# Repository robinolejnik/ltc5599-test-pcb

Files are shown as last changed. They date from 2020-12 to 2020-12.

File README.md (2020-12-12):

# ltc5599-test-pcb
This is a test PCB for the LTC5599 30 MHz to 1300 MHz Low Power Direct Quadrature Modulator.

[Schematic](https://raw.githubusercontent.com/robinolejnik/ltc5599-test-pcb/master/ltc5599-test-pcb.pdf)

[Interactive BOM](https://htmlpreview.github.io/?https://github.com/robinolejnik/ltc5599-test-pcb/blob/master/bom/ibom.html)

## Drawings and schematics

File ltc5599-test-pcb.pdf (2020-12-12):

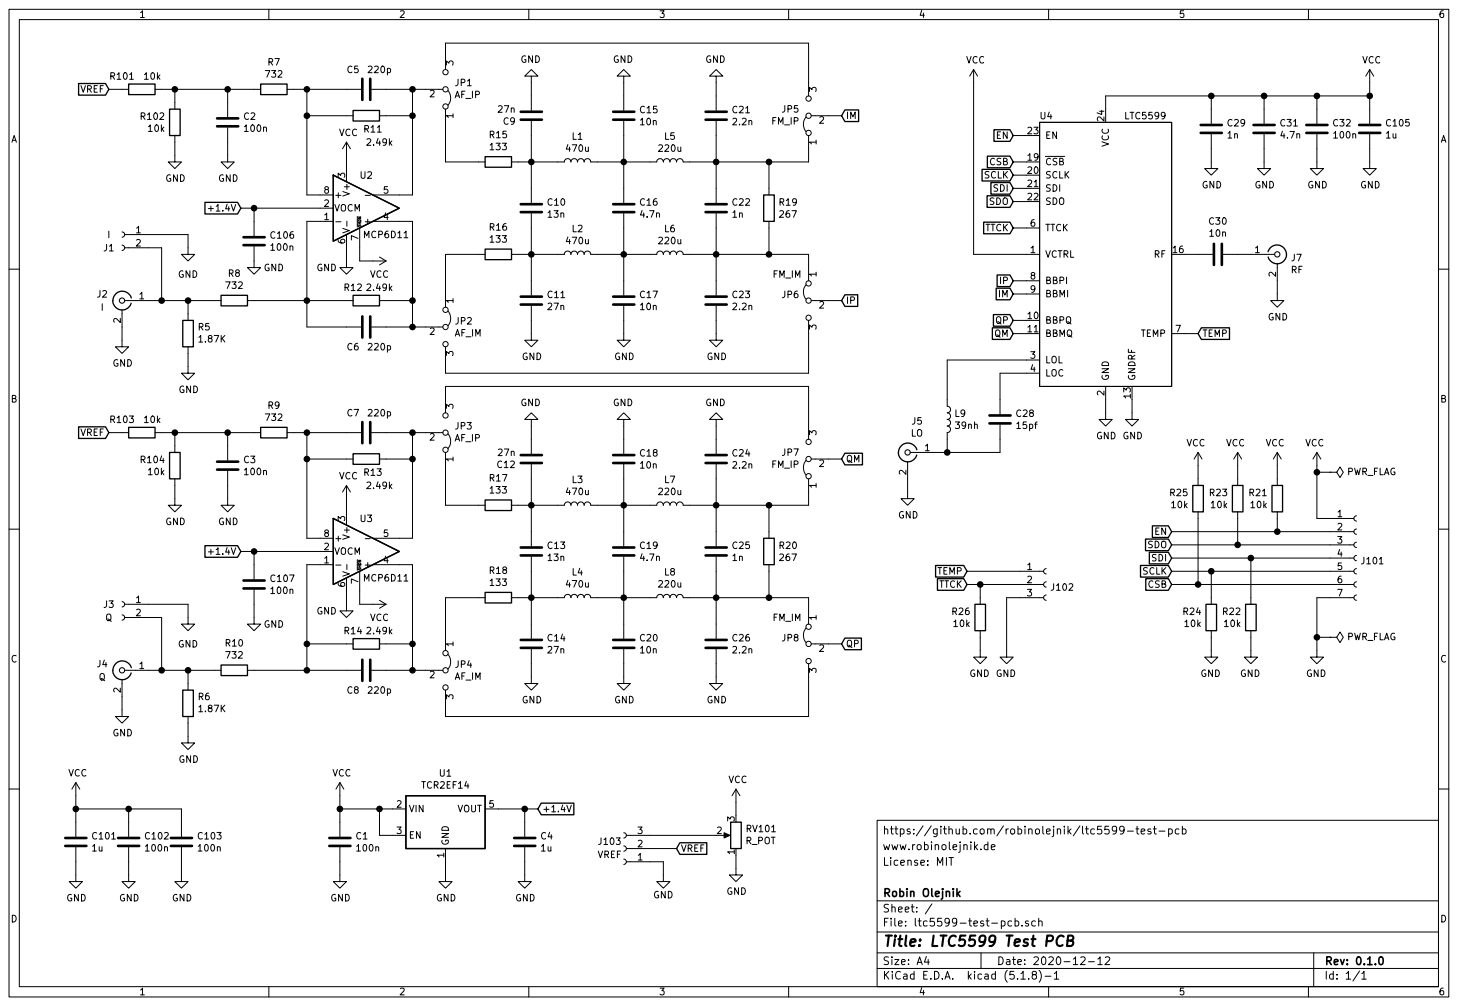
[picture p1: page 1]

2 SCLK 20 SDI 21 SDO 22 EN 23 VCC 24

https://github.com/robinolejnik/ltc5599-test-pcb
License: MIT www.robinolejnik.de

File: ltc5599-test-pcb.sch Sheet: / Robin Olejnik

Id: 1/1 Title: LTC5599 Test PCB

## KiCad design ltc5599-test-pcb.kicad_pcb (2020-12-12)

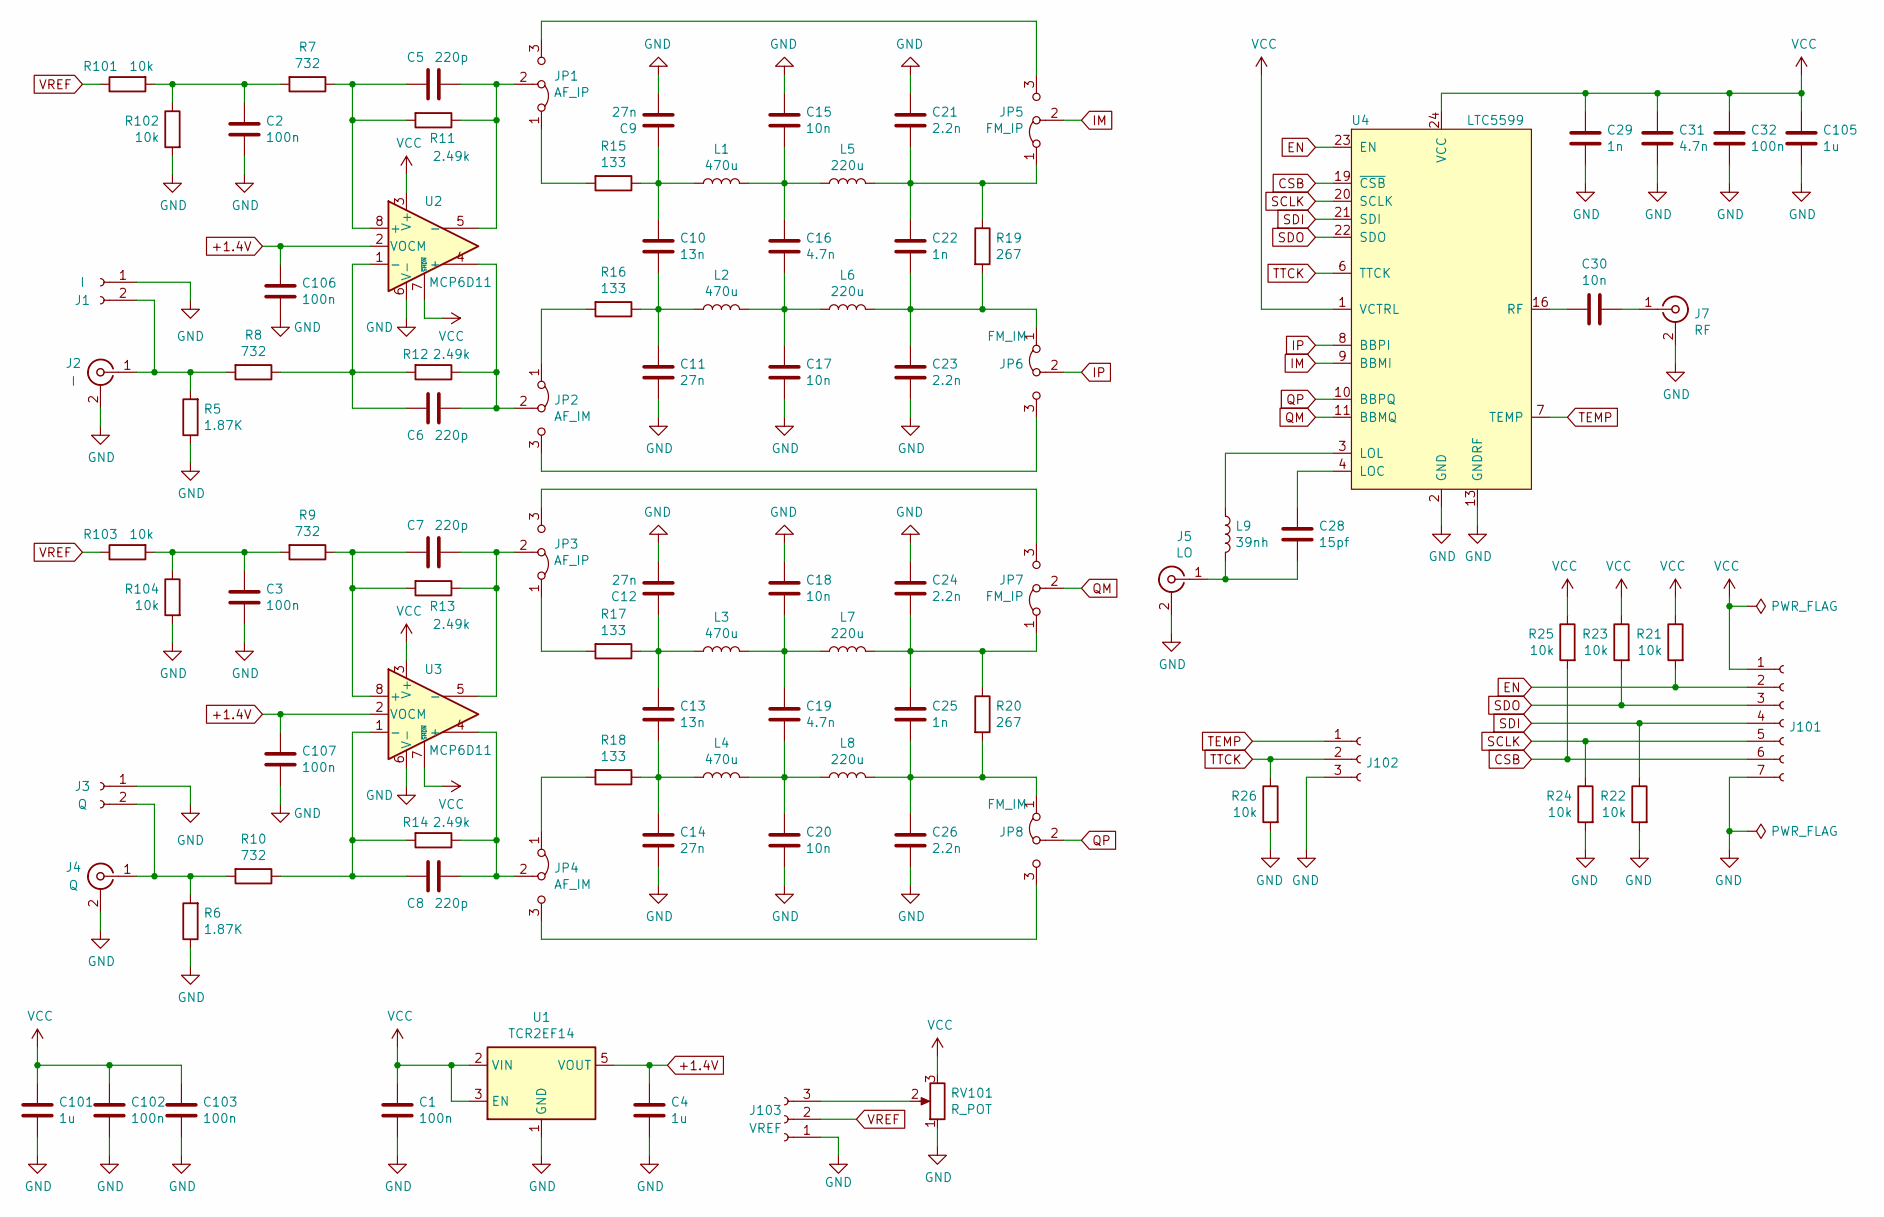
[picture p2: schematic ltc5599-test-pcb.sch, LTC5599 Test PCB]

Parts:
C1, C2, C3, C32, C102, C103, C106, C107: 100n; C_0805_2012Metric
C4, C101, C105: 1u; C_0805_2012Metric
C5, C6, C7, C8: 220p; C_0603_1608Metric; Mouser 603-CC603GRNPO9BN221
C9, C11, C12, C14: 27n; C_0603_1608Metric; Mouser 603-CC603JRX7R9BB273
C10, C13: 13n; C_0805_2012Metric; Mouser 81-GRM2195C1H133JA1D
C15, C17, C18, C20, C30: 10n; C_0603_1608Metric; Mouser 80-C0603C103J5R
C16, C19, C31: 4.7n; C_0603_1608Metric; Mouser 80-C0603C472F8HACTU
C21, C23, C24, C26: 2.2n; C_0603_1608Metric; Mouser 81-GCM1885C1H222FA6D
C22, C25, C29: 1n; C_0603_1608Metric; Mouser 603-CC603GRNPO9BN102
C28: 15pf; C_0603_1608Metric; Mouser 609-251R14S150JV4T
J1: I; PinHeader_1x02_P2.54mm_Vertical
J2: I; SMA_Amphenol_132289_EdgeMount
J3: Q; PinHeader_1x02_P2.54mm_Vertical
J4: Q; SMA_Amphenol_132289_EdgeMount
J5: LO; SMA_Amphenol_132289_EdgeMount
J7: RF; SMA_Amphenol_132289_EdgeMount
J101: Conn_01x07_Female; PinHeader_1x07_P2.54mm_Vertical
J102: Conn_01x03_Female; PinHeader_1x03_P2.54mm_Vertical
J103: VREF; PinHeader_1x03_P2.54mm_Vertical
JP1, JP3: AF_IP; PinHeader_1x03_P2.54mm_Vertical
JP2, JP4: AF_IM; PinHeader_1x03_P2.54mm_Vertical
JP5, JP7: FM_IP; PinHeader_1x03_P2.54mm_Vertical
JP6, JP8: FM_IM; PinHeader_1x03_P2.54mm_Vertical
L1, L2, L3, L4: 470u; L_Bourns-SRR7045; Mouser 652-SRR7045-471M
L5, L6, L7, L8: 220u; L_Bourns-SRR7045; Mouser 652-SRR7045-221M
L9: 39nh; L_0603_1608Metric; Mouser 81-LQW18AS39NG00D
R5, R6: 1.87K; R_0603_1608Metric
R7, R8, R9, R10: 732; R_0603_1608Metric; Mouser 652-CR0603FX-7320ELF
R11, R12, R13, R14: 2.49k; R_0603_1608Metric; Mouser 652-CR0603FX-2491ELF
R15, R16, R17, R18: 133; R_0603_1608Metric; Mouser 603-RC0603FR-07133RL
R19, R20: 267; R_0603_1608Metric; Mouser 603-RC0603FR-07267RL
R21, R22, R23, R24, R25, R26, R101, R102, R103, R104: 10k; R_0805_2012Metric
RV101: R_POT; Potentiometer_ACP_CA9-H2,5_Horizontal
U1: TCR2EF14; TSOT-23-5; Mouser 757-TCR2EF14LMCT
U2, U3: MCP6D11; MSOP-8_3x3mm_P0.65mm; Mouser 579-MCP6D11T-E/MS
U4: LTC5599; QFN-24-1EP_4x4mm_P0.5mm_EP2.6x2.6mm

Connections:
+1.4V: C4.1, C106.1, C107.1, U1.5 (VOUT), U2.2 (VOCM), U3.2 (VOCM)
CSB: J101.6, R25.2, U4.19 (~CSB)
EN: J101.2, R21.2, U4.23 (EN)
GND: C1.2, C2.2, C3.2, C4.2, C9.2, C11.2, C12.2, C14.2, C15.1, C17.2, C18.1, C20.2, C21.1, C23.2, C24.1, C26.2, C29.2, C31.2, C32.2, C101.2, C102.2, C103.2, C105.2, C106.2, C107.2, J1.1, J2.2 (Ext), J3.1, J4.2 (Ext), J5.2 (Ext), J7.2 (Ext), J101.7, J102.3, J103.1, R5.1, R6.1, R22.2, R24.2, R26.2, R102.2, R104.2, RV101.1, U1.1 (GND), U2.6 (V-), U3.6 (V-), U4.2 (GND), U4.5 (GND), U4.12 (GND), U4.13 (GNDRF), U4.14 (GNDRF), U4.15 (GNDRF), U4.17 (GNDRF), U4.18 (GNDRF), U4.25 (GND)
IM: JP5.2 (C), U4.9 (BBMI)
IP: JP6.2 (C), U4.8 (BBPI)
unnamed: C2.1, R7.2, R101.2, R102.1
unnamed: C3.1, R9.2, R103.2, R104.1
unnamed: C5.1, JP1.2 (C), R11.1, U2.5 (-)
unnamed: C5.2, R7.1, R11.2, U2.8 (+)
unnamed: C6.1, JP2.2 (C), R12.1, U2.4 (+)
unnamed: C6.2, R8.1, R12.2, U2.1 (-)
unnamed: C7.1, JP3.2 (C), R13.1, U3.5 (-)
unnamed: C7.2, R9.1, R13.2, U3.8 (+)
unnamed: C8.1, JP4.2 (C), R14.1, U3.4 (+)
unnamed: C8.2, R10.1, R14.2, U3.1 (-)
unnamed: C9.1, C10.1, L1.1, R15.1
unnamed: C10.2, C11.1, L2.1, R16.1
unnamed: C12.1, C13.1, L3.1, R17.1
unnamed: C13.2, C14.1, L4.1, R18.1
unnamed: C15.2, C16.1, L1.2, L5.1
unnamed: C16.2, C17.1, L2.2, L6.1
unnamed: C18.2, C19.1, L3.2, L7.1
unnamed: C19.2, C20.1, L4.2, L8.1
unnamed: C21.2, C22.1, JP5.1 (A), L5.2, R19.1
unnamed: C22.2, C23.1, JP6.1 (A), L6.2, R19.2
unnamed: C24.2, C25.1, JP7.1 (A), L7.2, R20.1
unnamed: C25.2, C26.1, JP8.1 (A), L8.2, R20.2
unnamed: C28.1, U4.4 (LOC)
unnamed: C28.2, J5.1 (In), L9.2
unnamed: C30.1, J7.1 (In)
unnamed: C30.2, U4.16 (RF)
unnamed: J1.2, J2.1 (In), R5.2, R8.2
unnamed: J3.2, J4.1 (In), R6.2, R10.2
unnamed: J103.3, RV101.2
unnamed: JP1.1 (A), R15.2
unnamed: JP1.3 (B), JP5.3 (B)
unnamed: JP2.1 (A), R16.2
unnamed: JP2.3 (B), JP6.3 (B)
unnamed: JP3.1 (A), R17.2
unnamed: JP3.3 (B), JP7.3 (B)
unnamed: JP4.1 (A), R18.2
unnamed: JP4.3 (B), JP8.3 (B)
unnamed: L9.1, U4.3 (LOL)
QM: JP7.2 (C), U4.11 (BBMQ)
QP: JP8.2 (C), U4.10 (BBPQ)
SCLK: J101.5, R24.1, U4.20 (SCLK)
SDI: J101.4, R22.1, U4.21 (SDI)
SDO: J101.3, R23.2, U4.22 (SDO)
TEMP: J102.1, U4.7 (TEMP)
TTCK: J102.2, R26.1, U4.6 (TTCK)
VCC: C1.1, C29.1, C31.1, C32.1, C101.1, C102.1, C103.1, C105.1, J101.1, R21.1, R23.1, R25.1, RV101.3, U1.2 (VIN), U1.3 (EN), U2.3 (V+), U2.7 (~SHDN), U3.3 (V+), U3.7 (~SHDN), U4.1 (VCTRL), U4.24 (VCC)
VREF: J103.2, R101.1, R103.1

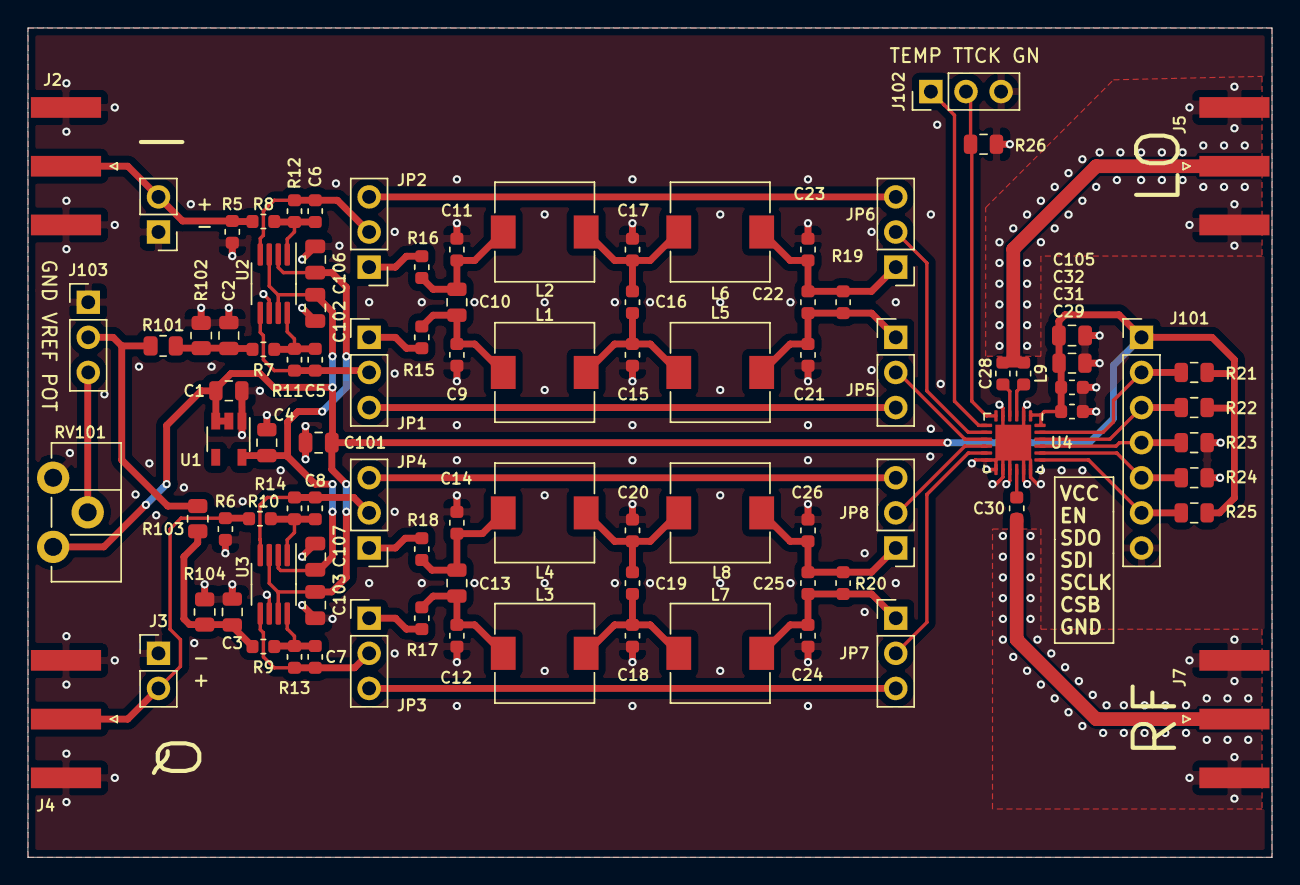
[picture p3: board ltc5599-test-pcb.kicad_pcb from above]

Board: 2 copper layers, 90.0 x 60.0 mm, 94 parts (0 on the bottom side), 53 nets.
